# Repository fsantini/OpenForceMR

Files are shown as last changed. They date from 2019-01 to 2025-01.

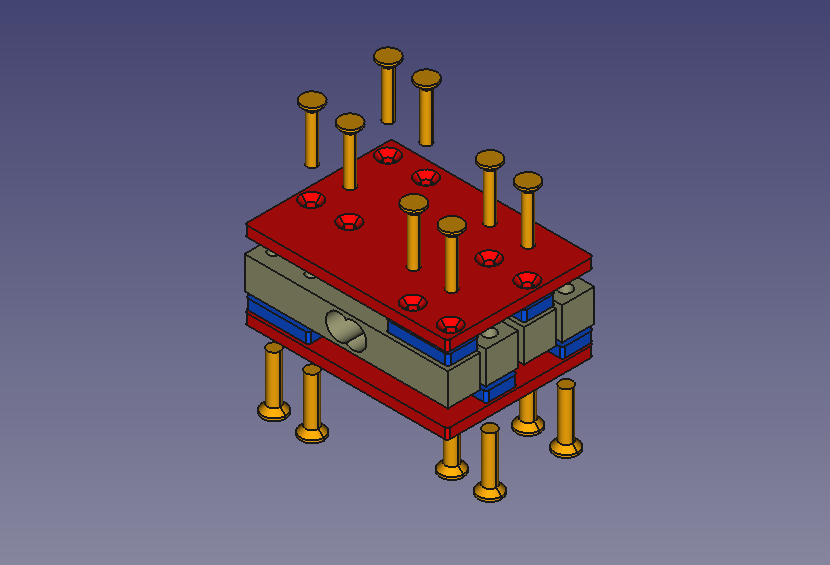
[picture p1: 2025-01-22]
Instructions_src/Assembly_pic.png

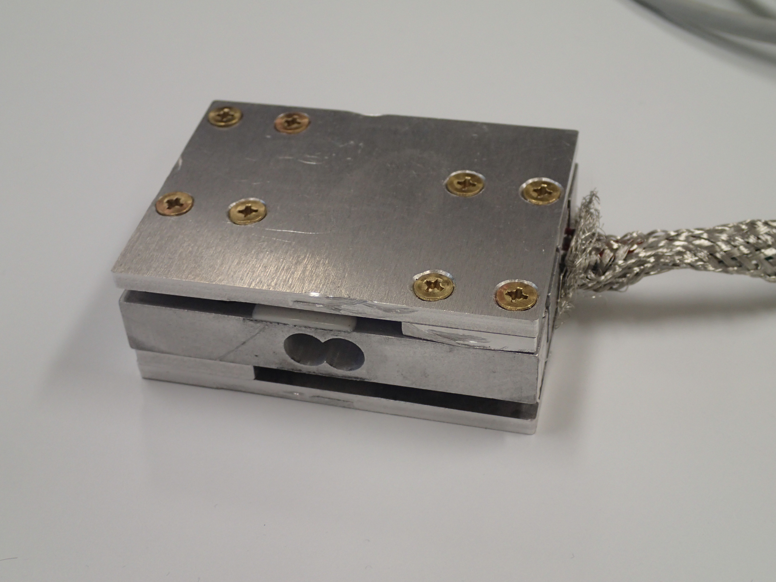
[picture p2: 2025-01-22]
Instructions_src/P7260583.JPG

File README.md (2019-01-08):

OpenForce MR
=================

This repository contains all the information to build the OpenForceSense MR force sensor, an MR-Compatible force sensor composed of cheap, off-the shelf components. This sensor, the associated files, the arduino firmware, and the host software included in this repository is open-source, distributed under the GNU General Programming License (GPL) v3.

Please see the file `instructions.pdf` to begin.

License
=======

All the files in this repository are copyrighted by Francesco Santini <francesco.santini@unibas.ch> and subject to the GNU General Programming License (GPL) v3. Please see the LICENSE file for details.

The Arduino code contains the HX711 library, available at https://github.com/bogde/HX711 and released under a GPLv2 license.

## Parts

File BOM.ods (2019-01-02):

 | Quantity | Price per item (USD) | Total | Notes
Sensor
Aluminum Plate (6082-T651) 150x150x4mm | 1 | 14.5 | 14.5
Brass Screws M4x20 Countersunk | 8 |  | 1.99 | Price for 10
Brass Screws M5x20 Countersunk | 8 |  | 2.99 | Price for 10
TAL220 Parallel Beam Load Cell – 20Kg | 4 | 3.95 | 15.8
8mm flat tin-plated copper shielding tube | 1 | 16 | 16
Shielded LAN Patch cable 10m | 1 | 14.59 | 14.59
Arduino shield
4-Pin stackable female header | 5 |  | 3.2 | Price for 20
6-Pin stackable female header | 2 |  | 0.99 | Price for 10
Prototype PCB for Arduino UNO | 1 | 1.8 | 1.8
Arduino UNO | 1 | 24.95 | 24.95
RJ45 Female PCB connector | 1 |  | 3.35 | Price for 10
HX711 with breakout board | 1 | 1.75 | 1.75
Misc
Aluminum wrap
Cable ties
Heat shrink tubing
Grand total |  |  | 101.91

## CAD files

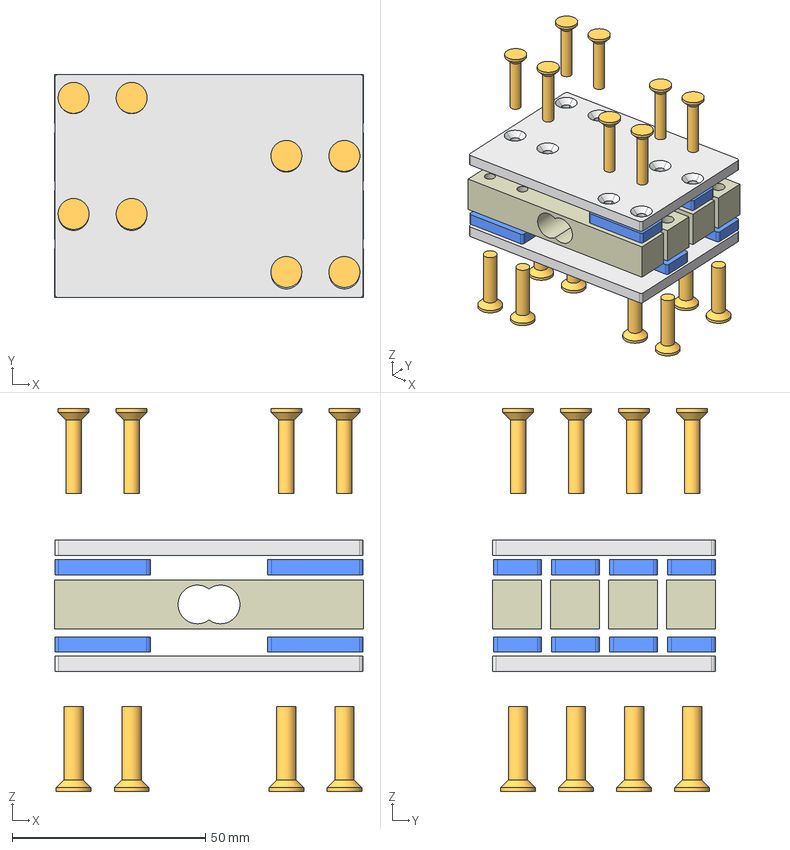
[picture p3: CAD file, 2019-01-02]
Frame/assmbly.fcstd
80.0 x 57.8 x 99.0 mm
Spacer_5mm_Array
Spacer_4mm_Array
LoadCell_Array
Chamfer_Plate_4mm
Chamfer_Plate_5mm
Array_M5_x8
Array_M4_x8

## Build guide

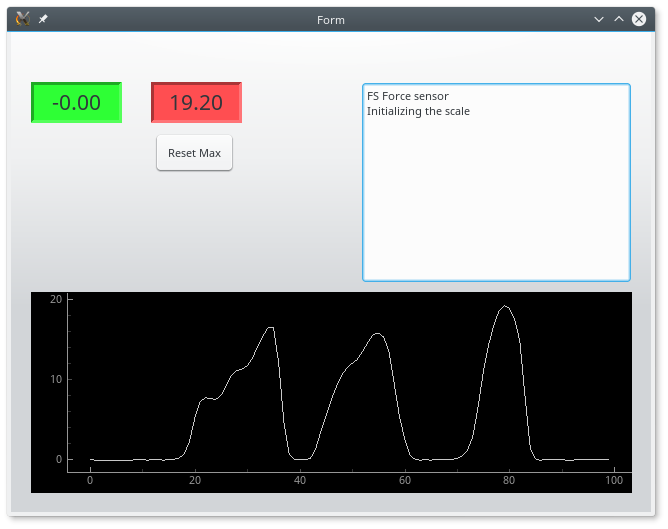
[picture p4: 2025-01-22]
Instructions_src/software_screenshot.png

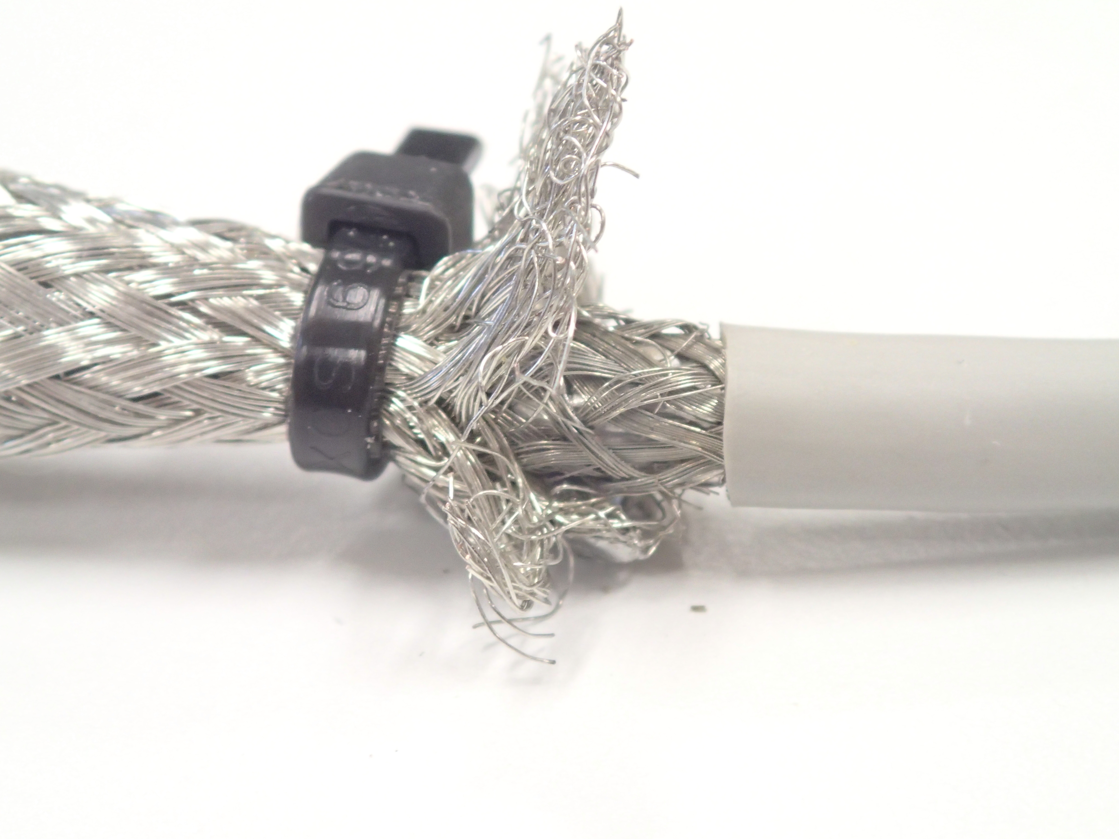
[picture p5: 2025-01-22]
Instructions_src/P7260584.JPG

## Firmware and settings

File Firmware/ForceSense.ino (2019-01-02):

#include "HX711.h"

/*  
    Copyright 2018 Francesco Santini <francesco.santini@unibas.ch>

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
    You should have received a copy of the GNU General Public License
    along with this program.  If not, see <http://www.gnu.org/licenses/>.
*/

#define DATA_PIN 7
#define CLK_PIN 6
#define SCALE 2457.3f

HX711 scale;

void setup() {
  Serial.begin(9600);
  Serial.println("FS Force sensor");

  Serial.println("Initializing the scale");
  // parameter "gain" is omitted; the default value 128 is used by the library (channel A)
  scale.begin(DATA_PIN, CLK_PIN);

  scale.set_scale(SCALE);
  scale.tare(20);  // set the tare
}

void loop() {
  if (Serial.available() > 0)
  {
    // look for a command
    String cmd = Serial.readStringUntil('\n');
    cmd.trim();
    if (cmd.equalsIgnoreCase("RESET"))
    {
      Serial.println("Resetting the tare");
      scale.tare(20);
      Serial.println("Done");
    }
  }
  // only execute if scale is ready to read a value
  if (scale.is_ready())
  {
    Serial.print("Force: ");
    float val = scale.get_units(); 
    Serial.println(val, 1);
  }
}

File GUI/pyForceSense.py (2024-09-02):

#!/usr/bin/env python3
# -*- coding: utf-8 -*-
"""
Created on Fri Aug 30 16:59:09 2024

@author: sabine
"""

import sys
import glob
import serial
import re
import time
from datetime import datetime
import os.path

import pyqtgraph as pg
from PyQt5.QtCore import *
from PyQt5.QtWidgets import *
from PyQt5.QtGui import *
from pyForceSense_ui import Ui_PyForceSenseWidget  # Assuming this was generated with pyuic5

BAUD = 9600
SERIAL_TIMER_INTERVAL = 20
MAXPLOTLENGTH = 100

forceStringPattern = re.compile(r'Force: ([-.0-9]+)')

def serial_ports():
    """ Lists serial port names """
    if sys.platform.startswith('win'):
        ports = ['COM%s' % (i + 1) for i in range(256)]
    elif sys.platform.startswith('linux') or sys.platform.startswith('cygwin'):
        ports = glob.glob('/dev/tty[A-Za-z]*')
    elif sys.platform.startswith('darwin'):
        ports = glob.glob('/dev/tty.*')
    else:
        raise EnvironmentError('Unsupported platform')

    result = []
    for port in ports:
        try:
            s = serial.Serial(port)
            s.close()
            result.append(port)
        except (OSError, serial.SerialException):
            pass
    return result

class PyForceSense(Ui_PyForceSenseWidget, QWidget):
    
    def __init__(self, parent=None):
        super(PyForceSense, self).__init__(parent)
        self.setupUi(self)
        self.maxForce = 0.0
        self.curForce = 0.0
        self.serialTimer = None
        self.resetMaxBtn.clicked.connect(self.resetMax)
        self.forcePlotObj = self.forcePlot.plot()
        self.plotData = []
        ports = serial_ports()
        self.trigPositions = []
        self.comportCombo.addItems(ports)
        self.connectButton.clicked.connect(self.serialConnect)
        self.autoNameButton.clicked.connect(self.autoName)
        self.logging = False
        self.logButton.clicked.connect(self.toggleLog)
        self.logFile = None
        self.clearButton.clicked.connect(lambda: self.serialOutputText.setPlainText(""))
        self.resetTareButton.clicked.connect(self.resetTare)
        self.serial = None
        self.autoName()
        self.yellowPen = pg.mkPen('y')
        
    def resetTare(self):
        if not self.checkSerialAvailable(): return
        ans = QMessageBox.warning(self, "Reset", "Resetting tare. Are you sure?", QMessageBox.Yes | QMessageBox.No)
        if ans == QMessageBox.Yes:
            self.serial.write(b"RESET\n")
        
    def toggleLog(self):
        if self.logging:
            self.logging = False
            self.logButton.setText("Start logging")
            self.logButton.setStyleSheet("")
            if self.logFile:
                self.serialOutputText.appendPlainText("Saving log")
                self.logFile.close()
                self.logFile = None
        else:
            if os.path.isfile(str(self.logName.text())):
                ret = QMessageBox.warning(self, "Warning", "LogFile exists! Overwrite?", QMessageBox.Yes | QMessageBox.No)
                if ret == QMessageBox.No:
                    return
            self.serialOutputText.appendPlainText("Opening log file: " + str(self.logName.text()))
            try:
                self.logFile = open(str(self.logName.text()), 'w')
                self.logFile.write("time,force,other\n")
            except:
                self.logFile = None
                self.serialOutputText.appendPlainText("Error opening log file")
                return
            self.logging = True
            self.logButton.setText("Stop logging")
            self.logButton.setStyleSheet("background-color: #FF5555;")
        
    def autoName(self):
        oldTxt = str(self.logName.text())
        pos = oldTxt.find('_')
        if pos < 0:
            baseStr = "LogFile"
        else:
            baseStr = oldTxt[:pos]
        self.logName.setText(baseStr + time.strftime("_%Y-%m-%d_%H.%M.%S.txt"))
        
    def serialConnect(self):
        if self.serial is not None:
            ans = QMessageBox.warning(self, "Disconnect", "Are you sure you want to disconnect?", QMessageBox.Yes | QMessageBox.No)
            if ans == QMessageBox.Yes:
                self.serialDisconnect()
            return
        try:
            self.serial = serial.Serial(str(self.comportCombo.currentText()), BAUD, timeout=0.5)
        except (OSError, serial.SerialException):
            self.serialOutputText.appendPlainText("Cannot open serial")
            self.serial = None
            return
        
        self.connectButton.setText("Disconnect")
        self.comportCombo.setEnabled(False)
        
        self.serialTimer = QTimer()
        self.serialTimer.timeout.connect(self.checkSerial)
        self.serialTimer.start(SERIAL_TIMER_INTERVAL)

    def serialDisconnect(self):
        self.connectButton.setText("Connect")
        self.comportCombo.setEnabled(True)
        if self.serialTimer: self.serialTimer.stop()
        self.serial = None
        
    def checkSerialAvailable(self):
        if not self.serial or not self.serial.readable():
            self.serialDisconnect()
            return False
        return True

    def checkSerial(self):
        if not self.checkSerialAvailable(): return
        if self.serial.in_waiting:
            serStr = self.serial.readline().strip()
            self.processSerial(serStr.decode())

    def makeLine(self, value):
        line = pg.InfiniteLine(movable=False, angle=90, pen=self.yellowPen, pos=value)
        self.forcePlot.addItem(line)
        return line
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

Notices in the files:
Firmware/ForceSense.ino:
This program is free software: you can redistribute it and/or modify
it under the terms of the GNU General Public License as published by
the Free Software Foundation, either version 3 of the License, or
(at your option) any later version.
